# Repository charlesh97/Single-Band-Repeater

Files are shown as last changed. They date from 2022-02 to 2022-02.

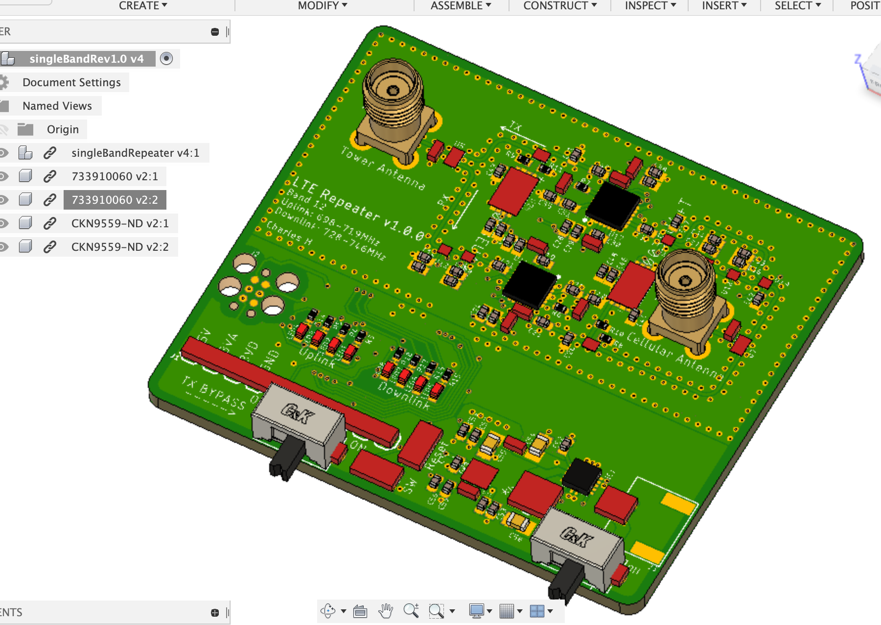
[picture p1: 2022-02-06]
Screen Shot 2020-11-10 at 12.03.37 PM.png

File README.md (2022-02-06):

# Single Band Repeater
## Uplink 698-719MHz
## Downlink 728-746MHz

Archived project. [Schematic](https://gitlab.com/chood2/single-band-repeater/-/blob/main/singleBandRepeater.pdf),[PCB](https://gitlab.com/chood2/single-band-repeater/-/blob/main/Screen%20Shot%202020-11-10%20at%2012.03.37%20PM.png)

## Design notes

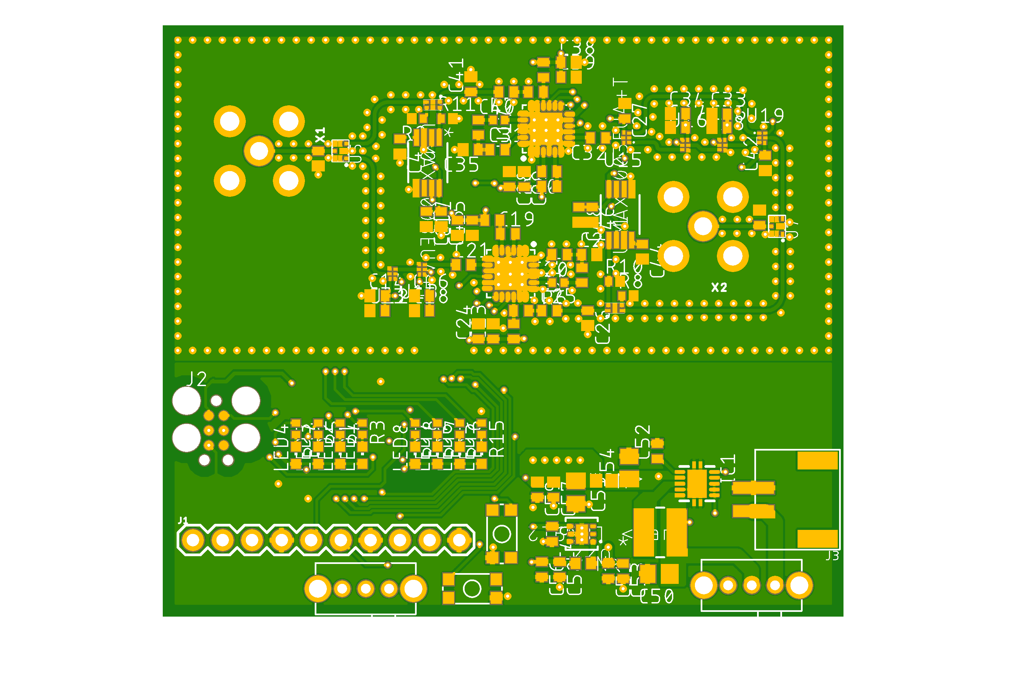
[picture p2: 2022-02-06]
singleBandRepeater.png

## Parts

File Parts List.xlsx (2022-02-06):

Band 5 Duplexer | https://www.digikey.com/product-detail/en/taiyo-yuden/D5DA881M5K2E4-Z/587-5655-1-ND/7251489
Band 12 Duplexer | https://www.digikey.com/product-detail/en/taiyo-yuden/D5DA737M5K2H2-Z/587-4563-1-ND/6024262
LNA | https://www.mouser.com/ProductDetail/Infineon-Technologies/BGA7L1N6E6327XTSA1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
VGA
Antenna | https://www.digikey.com/product-detail/en/taoglas-limited/TG-35-8113/931-1363-ND/5050760
Female Board Mount SMA | https://www.digikey.com/product-detail/en/molex/0733910070/WM5544-ND/1465166
Switch | https://www.infineon.com/dgdl/Infineon-BGS12SN6-DS-v02_03-EN.pdf?fileId=db3a30433f1b26e8013f2db58bc03856

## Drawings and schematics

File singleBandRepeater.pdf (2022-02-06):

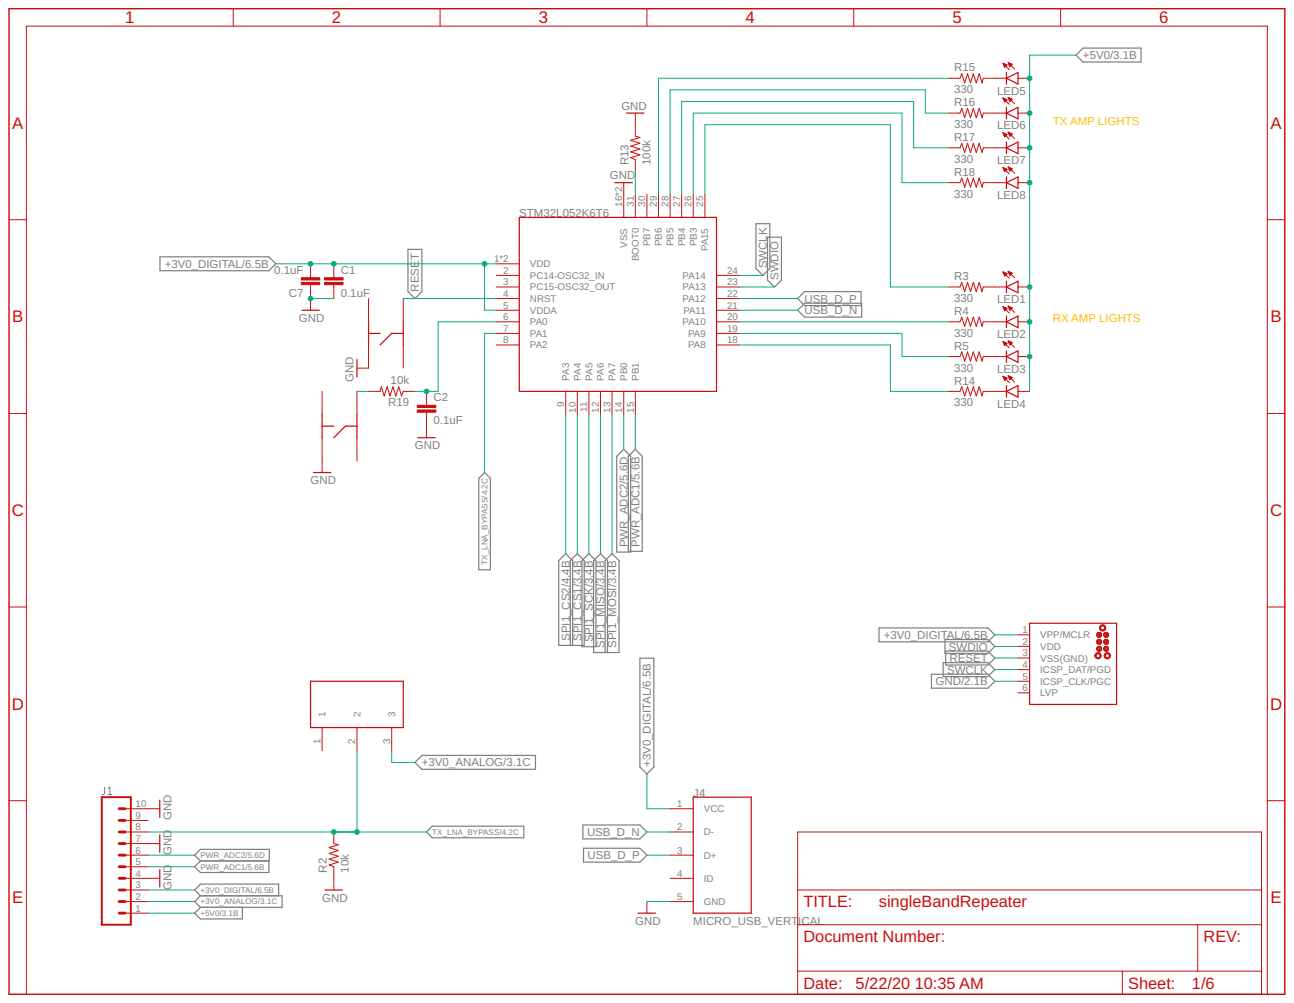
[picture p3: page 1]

Document Number: | REV:

Date: 5/22/20 10:35 AM | Sheet: 1/6

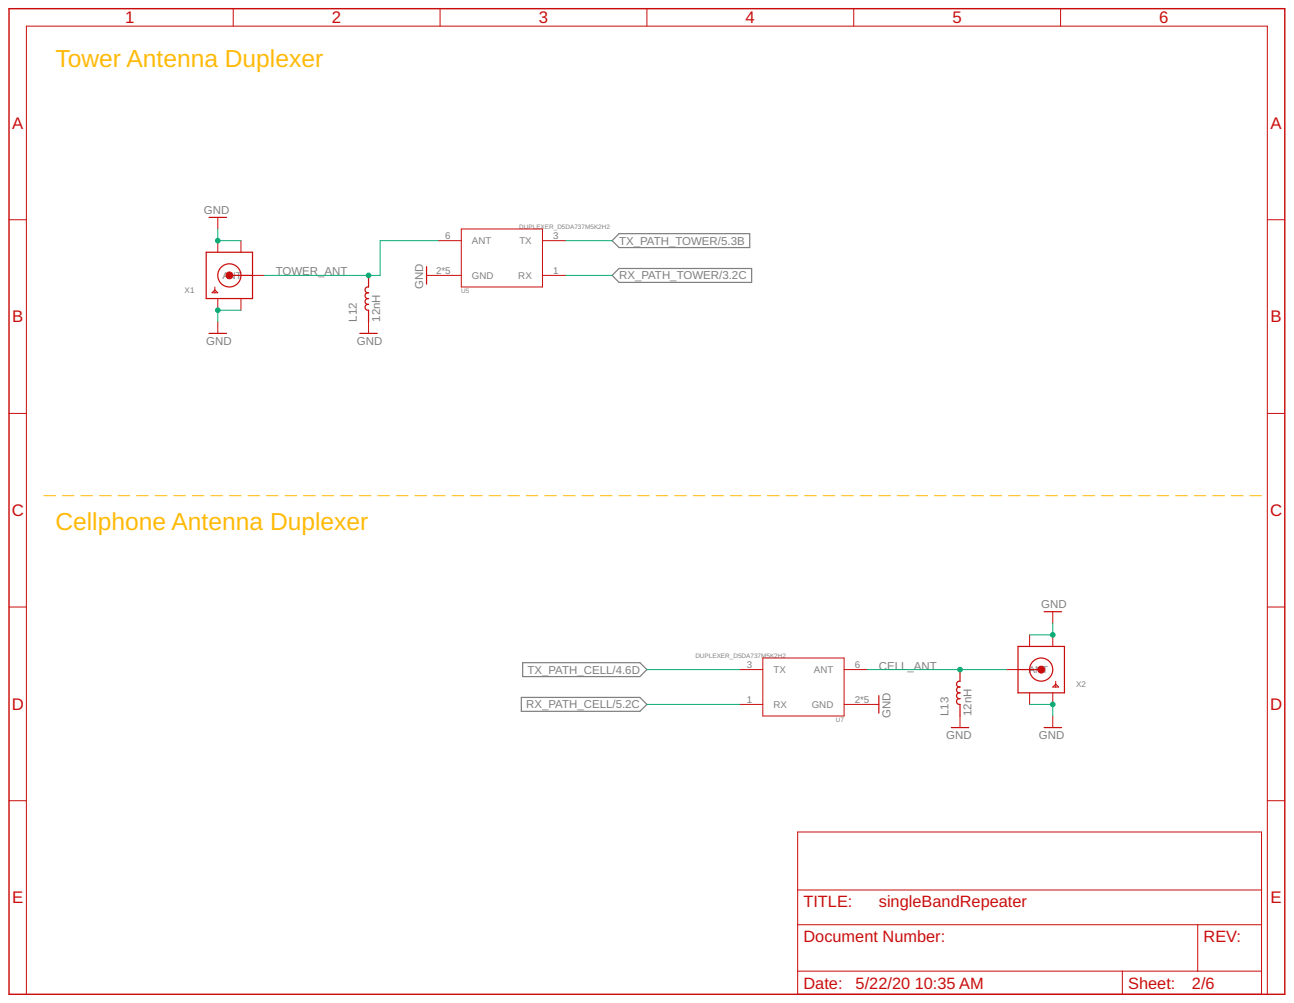
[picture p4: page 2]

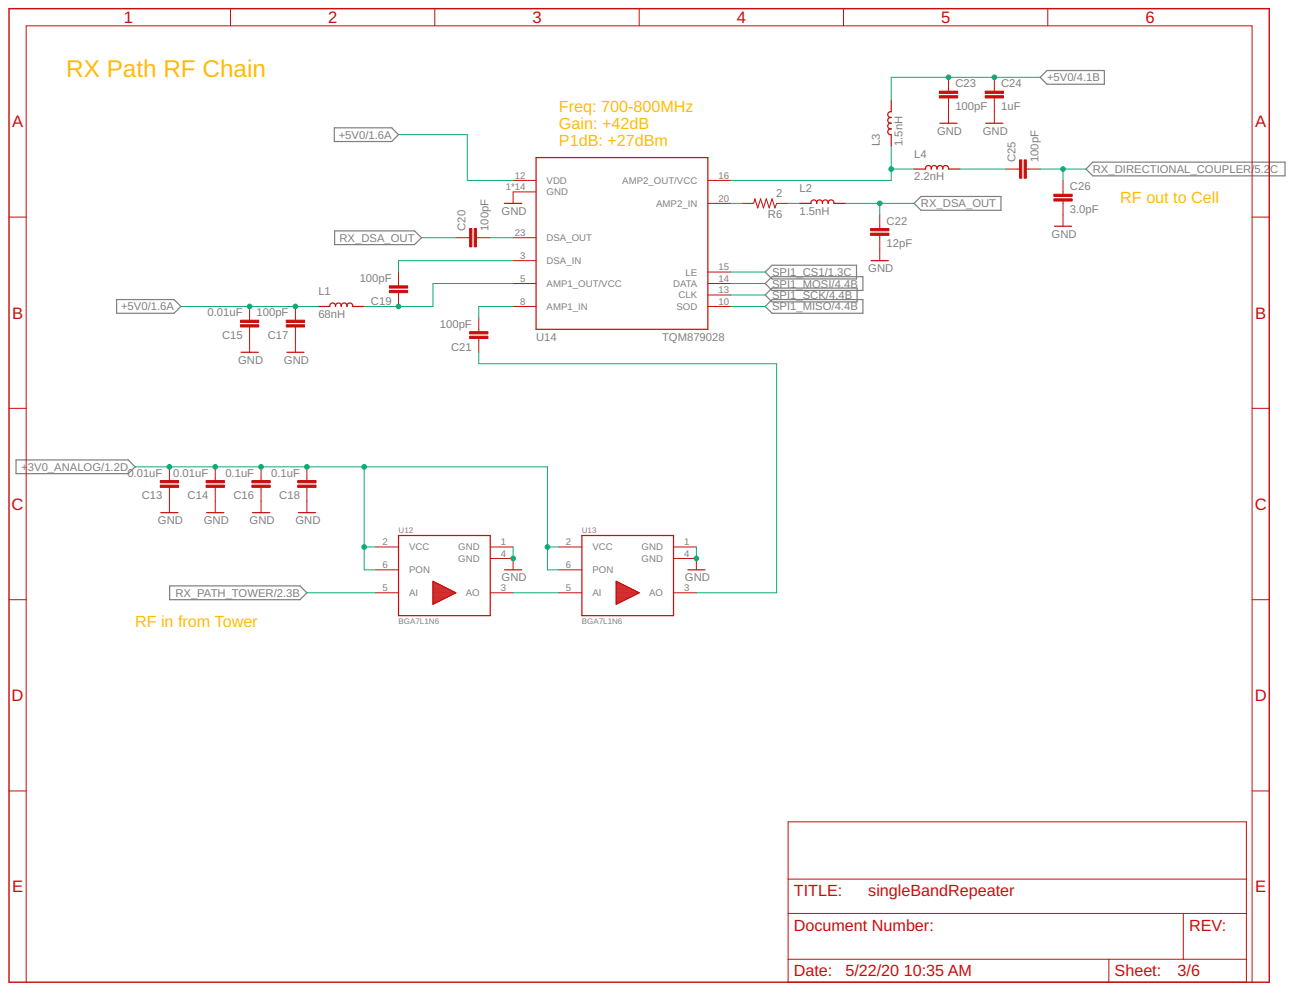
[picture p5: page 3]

RX Path RF Chain

RX_DIRECTIONAL_COUPLER/5.2C
RF out to Cell

RX_PATH_TOWER/2.3B
RF in from Tower

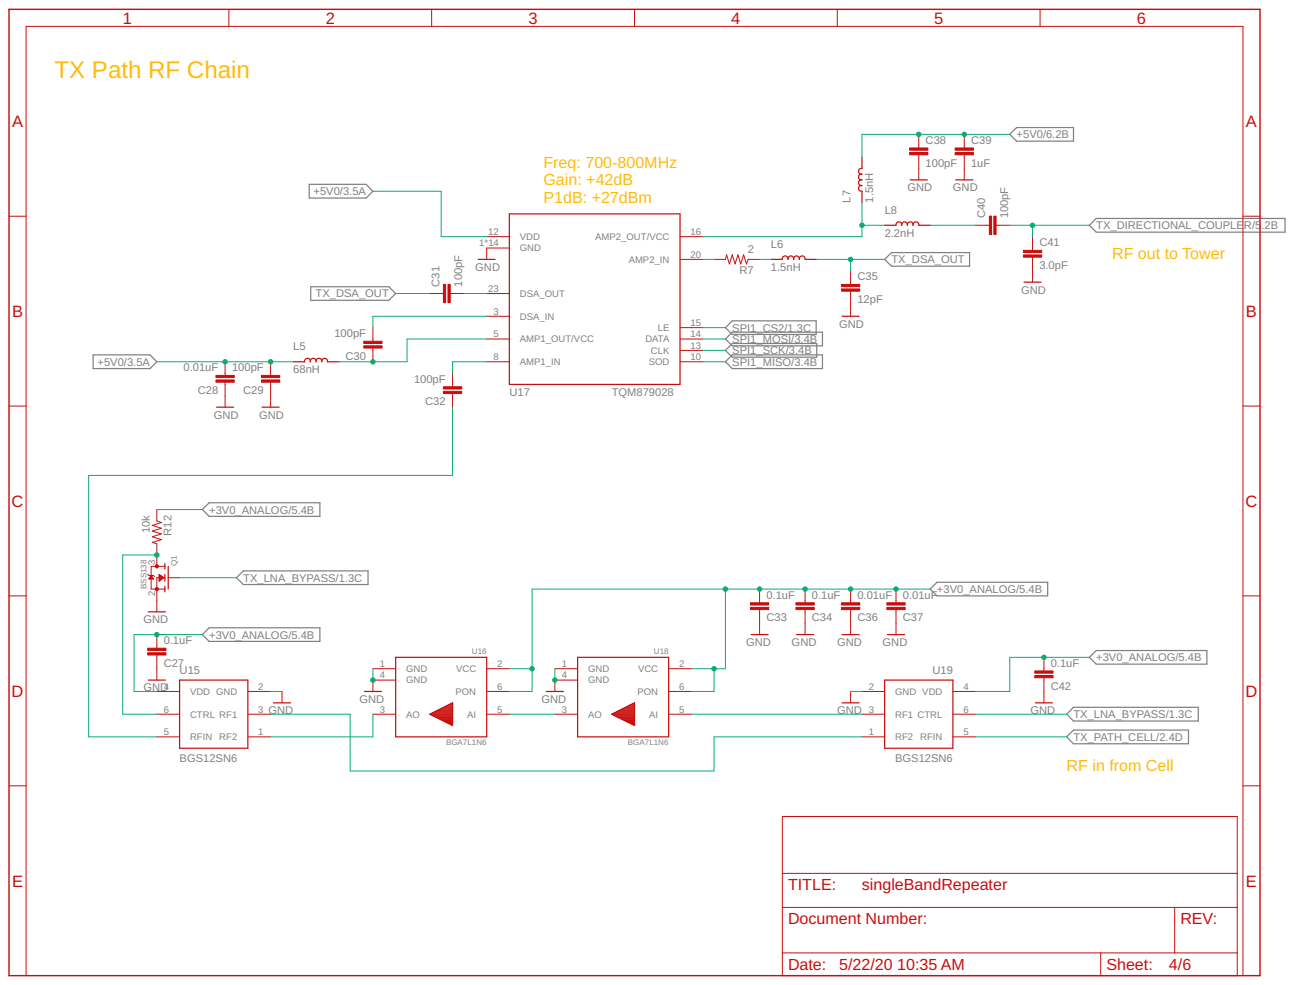
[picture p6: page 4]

TX Path RF Chain

TX_DIRECTIONAL_COUPLER/5.2B
RF out to Tower

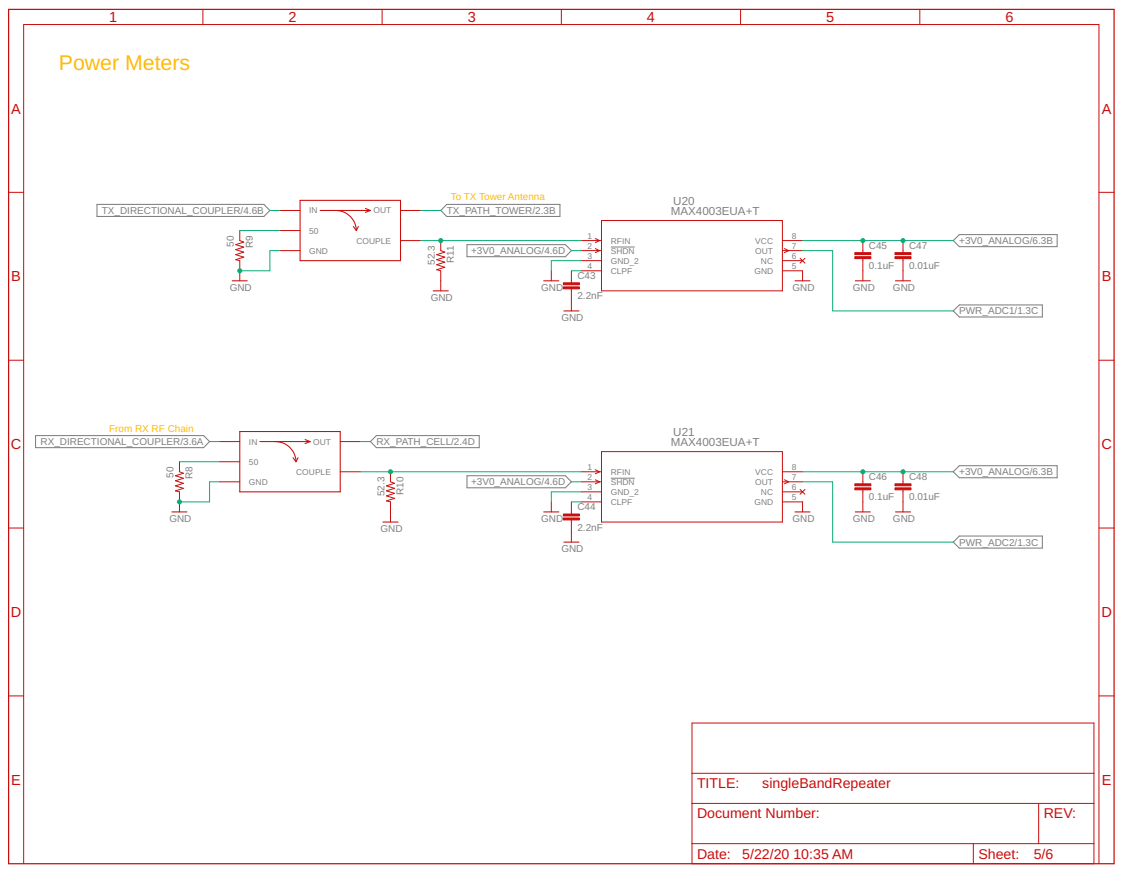
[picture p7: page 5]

To TX Tower Antenna
TX_PATH_TOWER/2.3B

From RX RF Chain

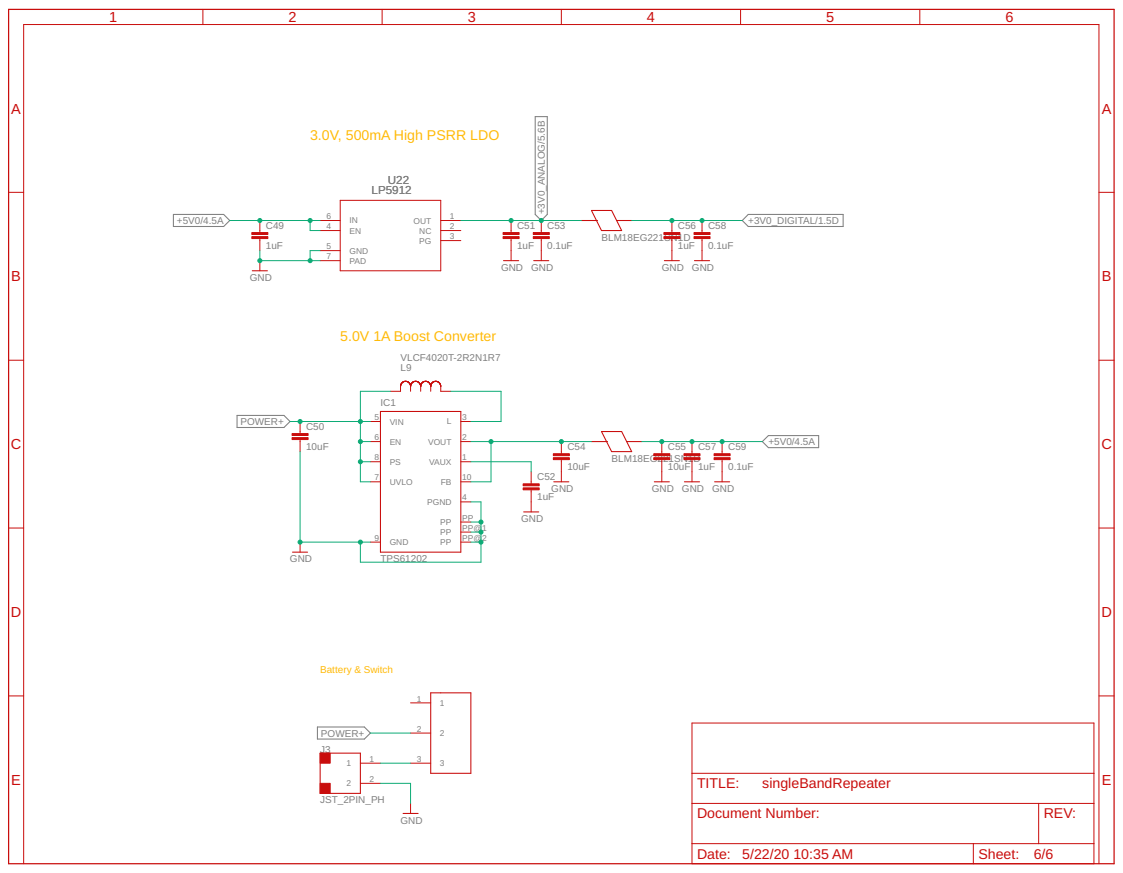
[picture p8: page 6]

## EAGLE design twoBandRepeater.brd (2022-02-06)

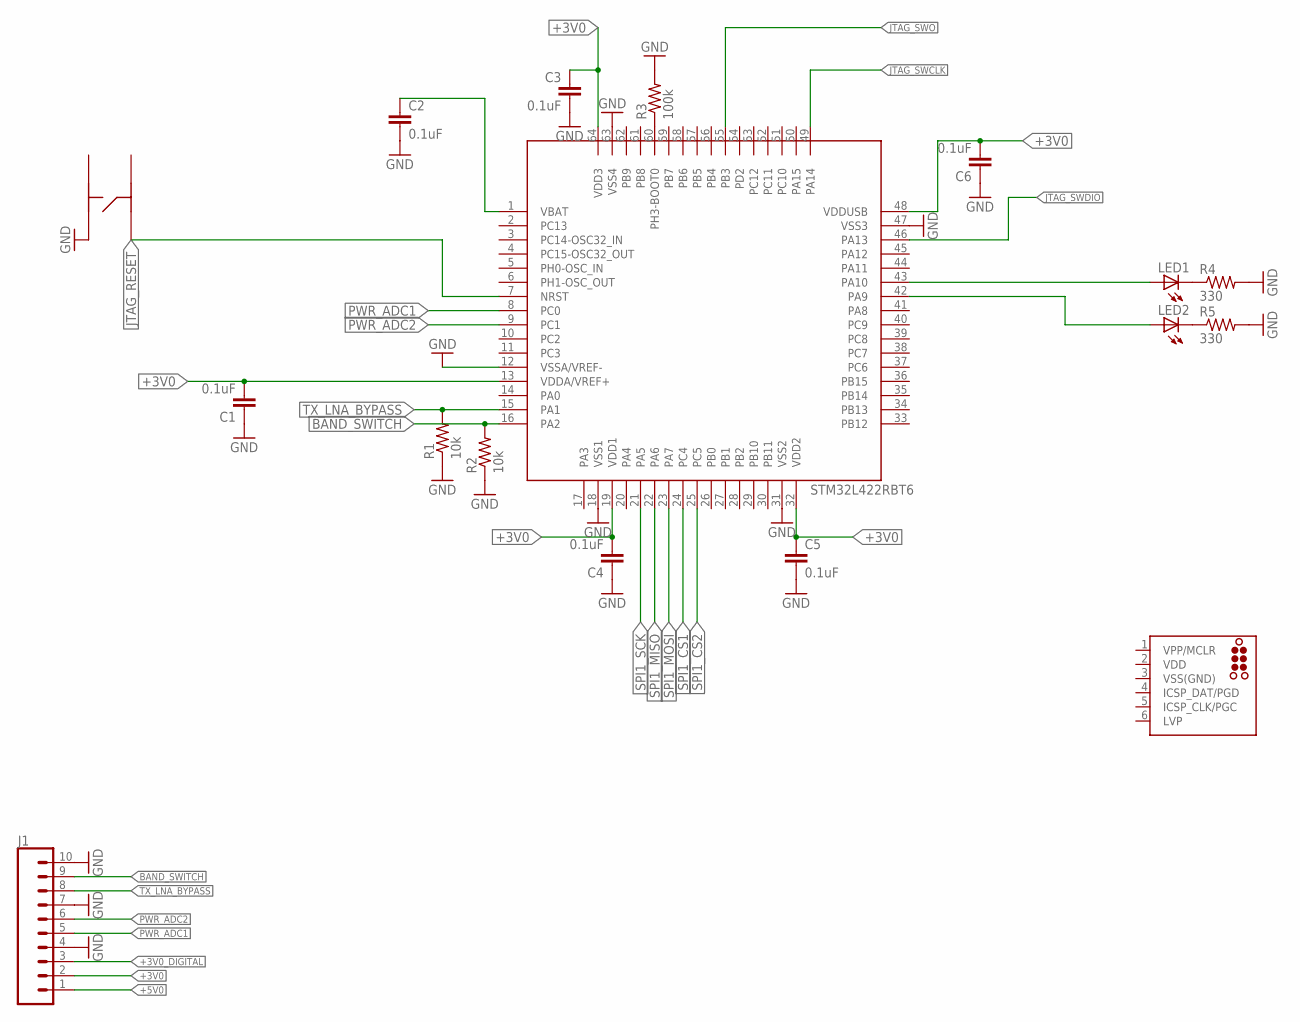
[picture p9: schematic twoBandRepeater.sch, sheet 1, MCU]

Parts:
C1, C2, C3, C4, C5, C6: 0.1uF; C0402
J1: CONN_10"; 1X10
J2: TC2030-MCP
LED1, LED2: LEDCHIP-LED0603; CHIP-LED0603
R1, R2: 10k; R0402
R3: 100k; R0402
R4, R5: 330; R0402
S1: KMR731NG
U1: STM32L422RBT6; QFP50P1200X1200X160-64

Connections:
+3V0: C1.2, C3.1, C4.2, C5.1, C6.2, J1.2, U1.13 (VDDA/VREF+), U1.19 (VDD1), U1.32 (VDD2), U1.48 (VDDUSB), U1.64 (VDD3); also elsewhere on the board
+3V0_DIGITAL: J1.3; also elsewhere on the board
+5V0: J1.1; also elsewhere on the board
BAND_SWITCH: J1.9, R2.2, U1.16 (PA2); also elsewhere on the board
GND: C1.1, C2.2, C3.2, C4.1, C5.2, C6.1, J1.4, J1.7, J1.10, R1.1, R2.1, R3.2, R4.2, R5.2, S1.P$3, U1.12 (VSSA/VREF-), U1.18 (VSS1), U1.31 (VSS2), U1.47 (VSS3), U1.63 (VSS4); also elsewhere on the board
JTAG_RESET: S1.P$2, U1.7 (NRST)
JTAG_SWCLK: U1.49 (PA14)
JTAG_SWDIO: U1.46 (PA13)
JTAG_SWO: U1.55 (PB3)
unnamed: C2.1, U1.1 (VBAT)
unnamed: LED1.C, R4.1
unnamed: LED2.C, R5.1
unnamed: LED2.A, U1.42 (PA9)
unnamed: LED1.A, U1.43 (PA10)
unnamed: R3.1, U1.60 (PH3-BOOT0)
PWR_ADC1: J1.5, U1.8 (PC0); also elsewhere on the board
PWR_ADC2: J1.6, U1.9 (PC1); also elsewhere on the board
SPI1_CS1: U1.24 (PC4); also elsewhere on the board
SPI1_CS2: U1.25 (PC5); also elsewhere on the board
SPI1_MISO: U1.22 (PA6); also elsewhere on the board
SPI1_MOSI: U1.23 (PA7); also elsewhere on the board
SPI1_SCK: U1.21 (PA5); also elsewhere on the board
TX_LNA_BYPASS: J1.8, R1.2, U1.15 (PA1); also elsewhere on the board
VDD: J2.2 (VDD)
VSS(GND): J2.3 (VSS(GND))

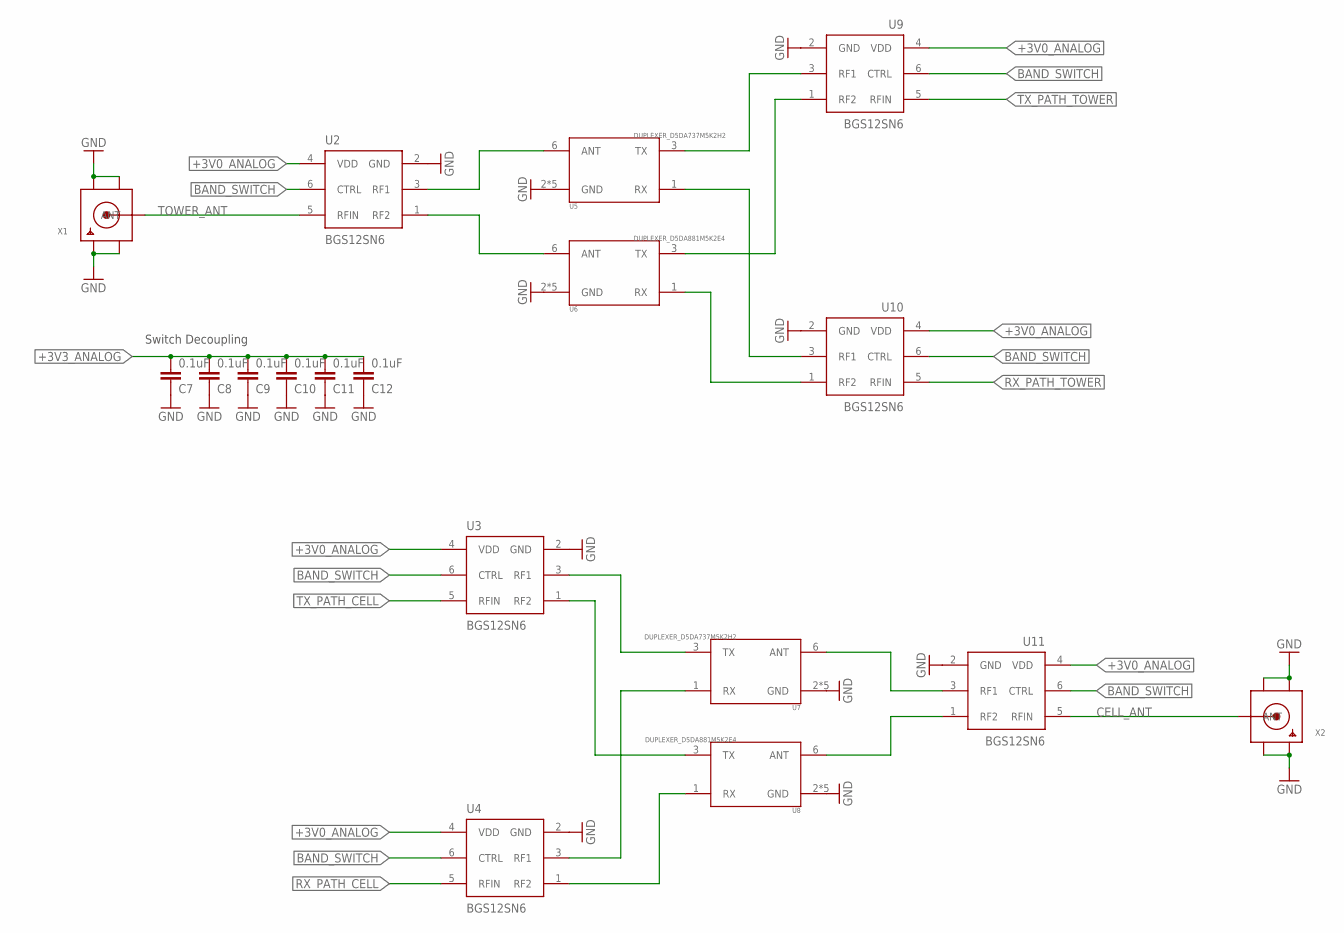
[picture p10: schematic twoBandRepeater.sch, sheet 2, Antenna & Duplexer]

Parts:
C7, C8, C9, C10, C11, C12: 0.1uF; C0402
U2, U3, U4, U9, U10, U11: BGS12SN6; INF-PG-TSNP-6-2
U5, U7: DUPLEXER_D5DA737M5K2H2; TAIYO_YUDEN_DUPLEX_1.8X1.4
U6, U8: DUPLEXER_D5DA881M5K2E4; TAIYO_YUDEN_DUPLEX_1.8X1.4
X1, X2: SMACONNECTORSMA_DIP; SMA_DIP

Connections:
+3V0_ANALOG: U2.4 (VDD), U3.4 (VDD), U4.4 (VDD), U9.4 (VDD), U10.4 (VDD), U11.4 (VDD); also elsewhere on the board
+3V3_ANALOG: C7.2, C8.2, C9.2, C10.2, C11.2, C12.2
BAND_SWITCH: U2.6 (CTRL), U3.6 (CTRL), U4.6 (CTRL), U9.6 (CTRL), U10.6 (CTRL), U11.6 (CTRL); also elsewhere on the board
CELL_ANT: U11.5 (RFIN), X2.ANTENNA (ANT)
GND: C7.1, C8.1, C9.1, C10.1, C11.1, C12.1, U2.2 (GND), U3.2 (GND), U4.2 (GND), U5.2 (GND), U5.4 (GND), U5.5 (GND), U5.7 (GND), U5.8 (GND), U6.2 (GND), U6.4 (GND), U6.5 (GND), U6.7 (GND), U6.8 (GND), U7.2 (GND), U7.4 (GND), U7.5 (GND), U7.7 (GND), U7.8 (GND), U8.2 (GND), U8.4 (GND), U8.5 (GND), U8.7 (GND), U8.8 (GND), U9.2 (GND), U10.2 (GND), U11.2 (GND), X1.GND1, X1.GND2, X1.GND3, X1.GND4, X2.GND1, X2.GND2, X2.GND3, X2.GND4; also elsewhere on the board
unnamed: U2.3 (RF1), U5.6 (ANT)
unnamed: U2.1 (RF2), U6.6 (ANT)
unnamed: U5.3 (TX), U9.3 (RF1)
unnamed: U6.3 (TX), U9.1 (RF2)
unnamed: U5.1 (RX), U10.3 (RF1)
unnamed: U6.1 (RX), U10.1 (RF2)
unnamed: U7.6 (ANT), U11.3 (RF1)
unnamed: U8.6 (ANT), U11.1 (RF2)
unnamed: U3.3 (RF1), U7.3 (TX)
unnamed: U3.1 (RF2), U8.3 (TX)
unnamed: U4.3 (RF1), U7.1 (RX)
unnamed: U4.1 (RF2), U8.1 (RX)
RX_PATH_CELL: U4.5 (RFIN); also elsewhere on the board
RX_PATH_TOWER: U10.5 (RFIN); also elsewhere on the board
TOWER_ANT: U2.5 (RFIN), X1.ANTENNA (ANT)
TX_PATH_CELL: U3.5 (RFIN); also elsewhere on the board
TX_PATH_TOWER: U9.5 (RFIN); also elsewhere on the board

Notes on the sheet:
Switch Decoupling

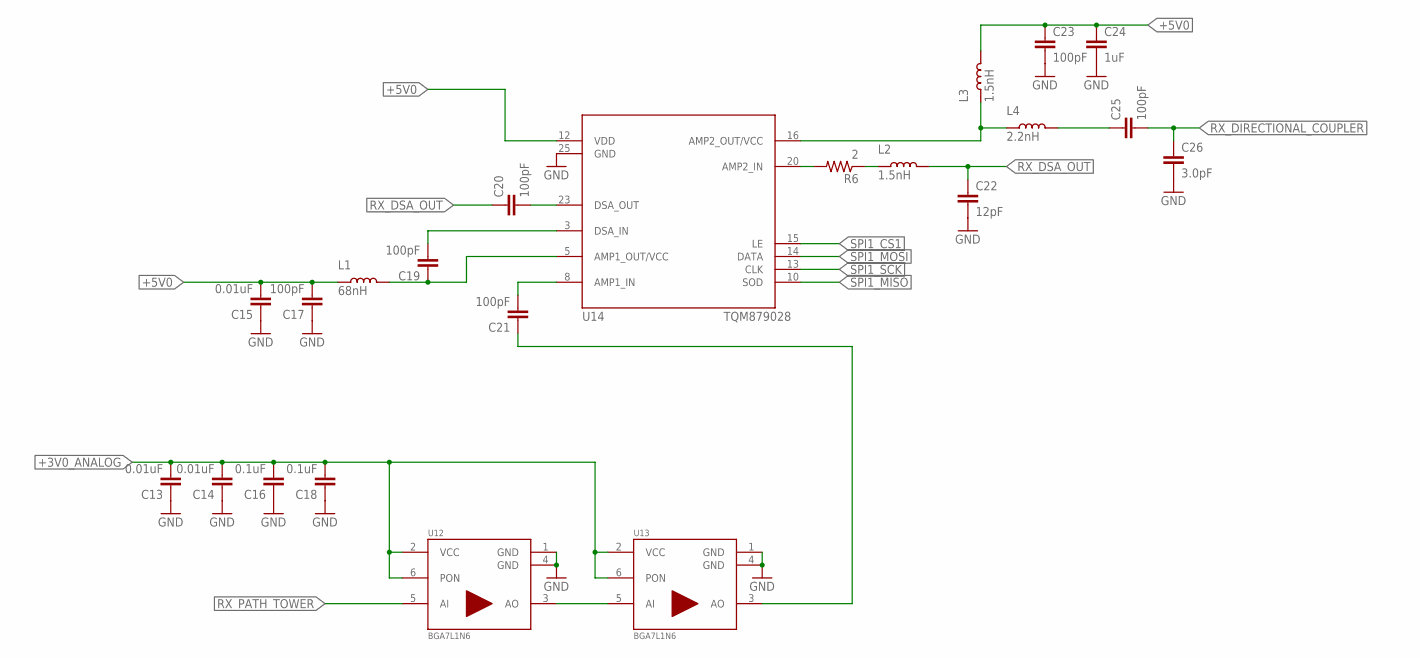
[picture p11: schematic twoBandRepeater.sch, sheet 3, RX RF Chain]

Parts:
C13, C14, C15: 0.01uF; C0402
C16, C18: 0.1uF; C0402
C17, C19, C20, C21, C23, C25: 100pF; C0402
C22: 12pF; C0402
C24: 1uF; C0402
C26: 3.0pF; C0402
L1: 68nH; 0402
L2, L3: 1.5nH; 0402
L4: 2.2nH; 0402
R6: 2; R0402
U12, U13: BGA7L1N6; INF-PG-TSNP-6-2
U14: TQM879028; QFN50P400X400X100-25T270N

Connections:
+3V0_ANALOG: C13.2, C14.2, C16.2, C18.2, U12.2 (VCC), U12.6 (PON), U13.2 (VCC), U13.6 (PON); also elsewhere on the board
+5V0: C15.2, C17.2, C23.1, C24.1, L1.1, L3.2, U14.12 (VDD); also elsewhere on the board
GND: C13.1, C14.1, C15.1, C16.1, C17.1, C18.1, C22.2, C23.2, C24.2, C26.2, U12.1 (GND), U12.4 (GND), U13.1 (GND), U13.4 (GND), U14.25 (GND); also elsewhere on the board
unnamed: U12.3 (AO), U13.5 (AI)
unnamed: C21.1, U13.3 (AO)
unnamed: C21.2, U14.8 (AMP1_IN)
unnamed: C19.1, L1.2, U14.5 (AMP1_OUT/VCC)
unnamed: C20.2, U14.23 (DSA_OUT)
unnamed: C19.2, U14.3 (DSA_IN)
unnamed: L3.1, L4.1, U14.16 (AMP2_OUT/VCC)
unnamed: L2.1, R6.1
unnamed: R6.2, U14.20 (AMP2_IN)
unnamed: C25.1, L4.2
RX_DIRECTIONAL_COUPLER: C25.2, C26.1; also elsewhere on the board
RX_DSA_OUT: C20.1, C22.1, L2.2
RX_PATH_TOWER: U12.5 (AI); also elsewhere on the board
SPI1_CS1: U14.15 (LE); also elsewhere on the board
SPI1_MISO: U14.10 (SOD); also elsewhere on the board
SPI1_MOSI: U14.14 (DATA); also elsewhere on the board
SPI1_SCK: U14.13 (CLK); also elsewhere on the board

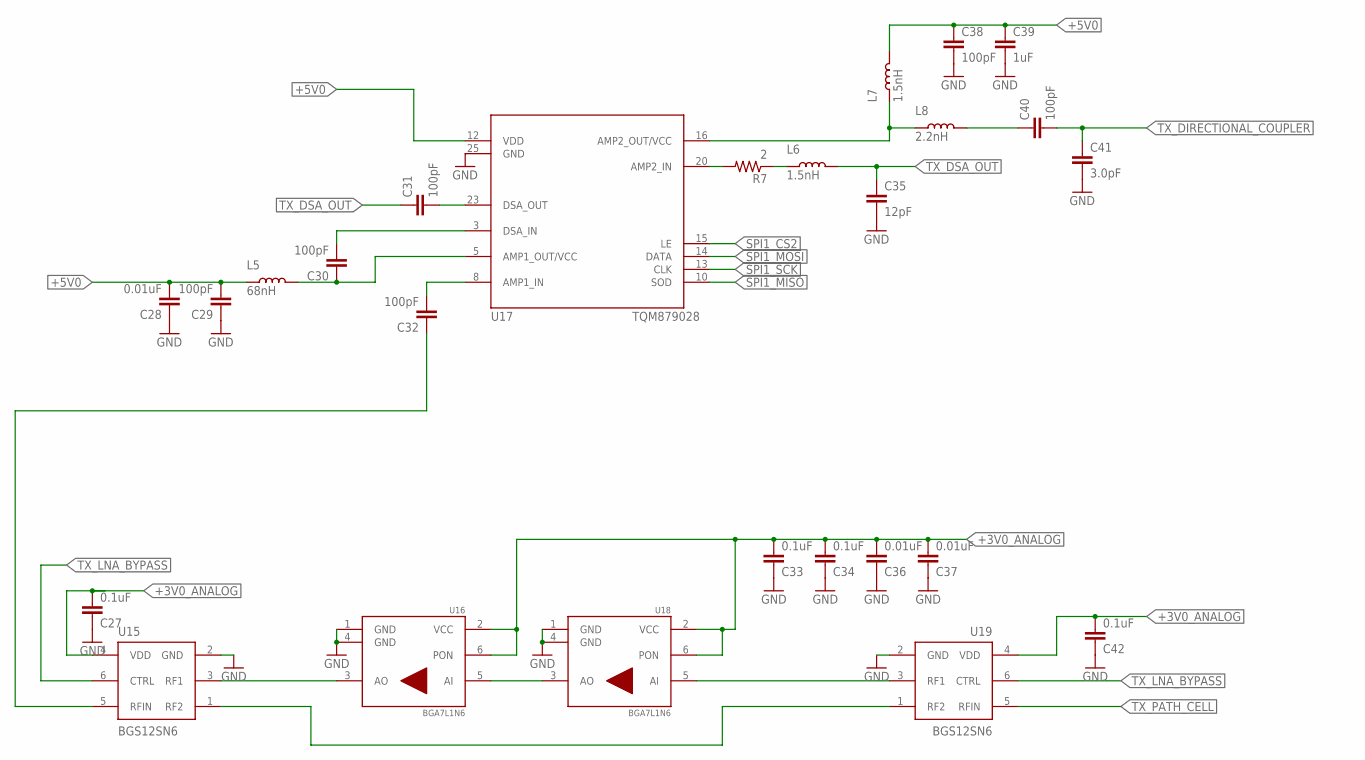
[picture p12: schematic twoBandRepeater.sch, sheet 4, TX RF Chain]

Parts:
C27, C33, C34, C42: 0.1uF; C0402
C28, C36, C37: 0.01uF; C0402
C29, C30, C31, C32, C38, C40: 100pF; C0402
C35: 12pF; C0402
C39: 1uF; C0402
C41: 3.0pF; C0402
L5: 68nH; 0402
L6, L7: 1.5nH; 0402
L8: 2.2nH; 0402
R7: 2; R0402
U15, U19: BGS12SN6; INF-PG-TSNP-6-2
U16, U18: BGA7L1N6; INF-PG-TSNP-6-2
U17: TQM879028; QFN50P400X400X100-25T270N

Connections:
+3V0_ANALOG: C27.2, C33.2, C34.2, C36.2, C37.2, C42.2, U15.4 (VDD), U16.2 (VCC), U16.6 (PON), U18.2 (VCC), U18.6 (PON), U19.4 (VDD); also elsewhere on the board
+5V0: C28.2, C29.2, C38.1, C39.1, L5.1, L7.2, U17.12 (VDD); also elsewhere on the board
GND: C27.1, C28.1, C29.1, C33.1, C34.1, C35.2, C36.1, C37.1, C38.2, C39.2, C41.2, C42.1, U15.2 (GND), U16.1 (GND), U16.4 (GND), U17.25 (GND), U18.1 (GND), U18.4 (GND), U19.2 (GND); also elsewhere on the board
unnamed: U16.5 (AI), U18.3 (AO)
unnamed: C32.2, U17.8 (AMP1_IN)
unnamed: C30.1, L5.2, U17.5 (AMP1_OUT/VCC)
unnamed: C30.2, U17.3 (DSA_IN)
unnamed: C31.2, U17.23 (DSA_OUT)
unnamed: L6.1, R7.1
unnamed: R7.2, U17.20 (AMP2_IN)
unnamed: L7.1, L8.1, U17.16 (AMP2_OUT/VCC)
unnamed: C40.1, L8.2
unnamed: U15.3 (RF1), U16.3 (AO)
unnamed: U18.5 (AI), U19.3 (RF1)
unnamed: U15.1 (RF2), U19.1 (RF2)
unnamed: C32.1, U15.5 (RFIN)
SPI1_CS2: U17.15 (LE); also elsewhere on the board
SPI1_MISO: U17.10 (SOD); also elsewhere on the board
SPI1_MOSI: U17.14 (DATA); also elsewhere on the board
SPI1_SCK: U17.13 (CLK); also elsewhere on the board
TX_DIRECTIONAL_COUPLER: C40.2, C41.1; also elsewhere on the board
TX_DSA_OUT: C31.1, C35.1, L6.2
TX_LNA_BYPASS: U15.6 (CTRL), U19.6 (CTRL); also elsewhere on the board
TX_PATH_CELL: U19.5 (RFIN); also elsewhere on the board

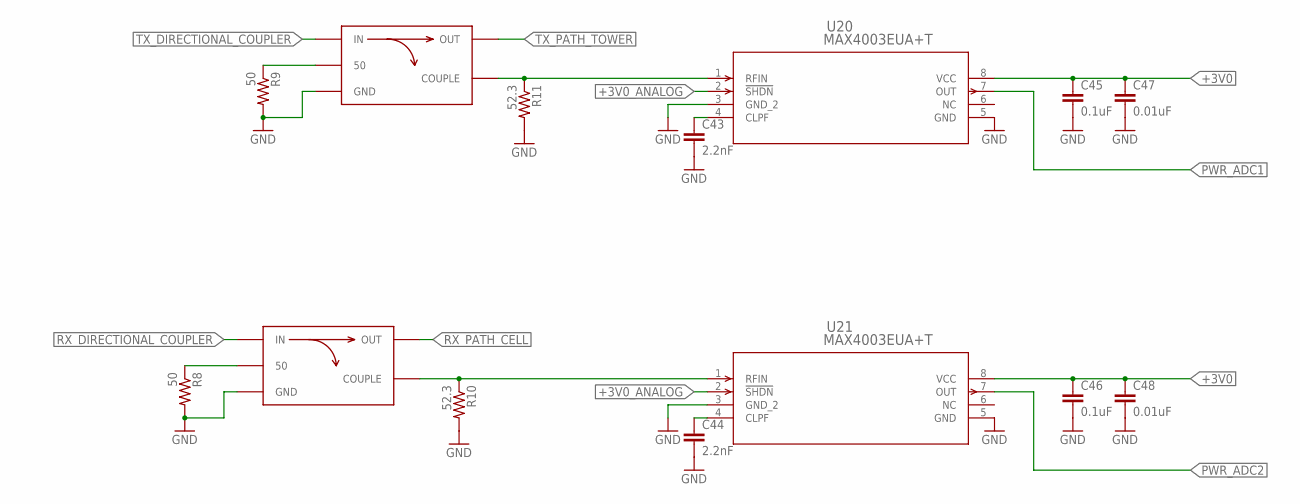
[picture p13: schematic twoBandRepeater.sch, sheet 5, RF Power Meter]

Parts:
C43, C44: 2.2nF; C0402
C45, C46: 0.1uF; C0402
C47, C48: 0.01uF; C0402
HY1, HY2: HHM22152A2
R8, R9: 50; R0402
R10, R11: 52.3; R0402
U20, U21: MAX4003EUA+T; 21-0036K

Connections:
+3V0: C45.1, C46.1, C47.1, C48.1, U20.8 (VCC), U21.8 (VCC); also elsewhere on the board
+3V0_ANALOG: U20.2 (!SHDN), U21.2 (!SHDN); also elsewhere on the board
GND: C43.2, C44.2, C45.2, C46.2, C47.2, C48.2, HY1.P$2 (GND), HY1.P$5 (GND), HY2.P$2 (GND), HY2.P$5 (GND), R8.2, R9.2, R10.2, R11.2, U20.3 (GND_2), U20.5 (GND), U21.3 (GND_2), U21.5 (GND); also elsewhere on the board
unnamed: HY2.P$4 (50), R9.1
unnamed: C43.1, U20.4 (CLPF)
unnamed: HY2.P$6 (COUPLE), R11.1, U20.1 (RFIN)
unnamed: HY1.P$4 (50), R8.1
unnamed: C44.1, U21.4 (CLPF)
unnamed: HY1.P$6 (COUPLE), R10.1, U21.1 (RFIN)
PWR_ADC1: U20.7 (OUT); also elsewhere on the board
PWR_ADC2: U21.7 (OUT); also elsewhere on the board
RX_DIRECTIONAL_COUPLER: HY1.P$1 (IN); also elsewhere on the board
RX_PATH_CELL: HY1.P$3 (OUT); also elsewhere on the board
TX_DIRECTIONAL_COUPLER: HY2.P$1 (IN); also elsewhere on the board
TX_PATH_TOWER: HY2.P$3 (OUT); also elsewhere on the board

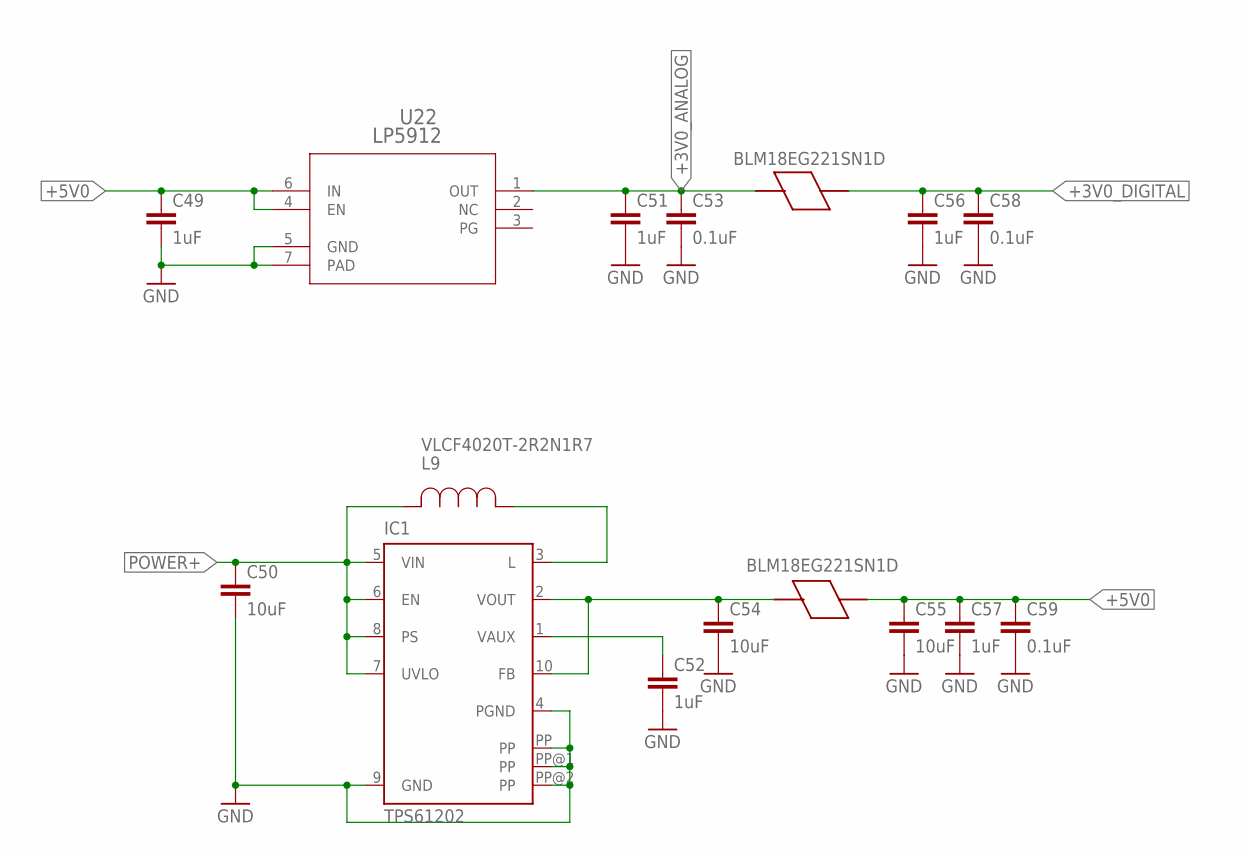
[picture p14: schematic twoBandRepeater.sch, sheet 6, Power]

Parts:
C49, C51, C52, C56, C57: 1uF; C0402
C50, C54, C55: 10uF; C0805
C53, C58, C59: 0.1uF; C0402
IC1: TPS61202; S-PDSO-N10
L9: VLCF4020T-2R2N1R7; IND_4028
L10, L11: BLM18EG221SN1D; IND_BLM18_0603
U22: LP5912; DRV0006A

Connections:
+3V0_ANALOG: C51.1, C53.1, L10.1, U22.1 (OUT); also elsewhere on the board
+3V0_DIGITAL: C56.1, C58.1, L10.2; also elsewhere on the board
+5V0: C49.1, C55.1, C57.1, C59.1, L11.2, U22.4 (EN), U22.6 (IN); also elsewhere on the board
GND: C49.2, C50.2, C51.2, C52.2, C53.2, C54.2, C55.2, C56.2, C57.2, C58.2, C59.2, IC1.4 (PGND), IC1.9 (GND), IC1.PP, IC1.PP@1 (PP), IC1.PP@2 (PP), U22.5 (GND), U22.7 (PAD); also elsewhere on the board
unnamed: IC1.3 (L), L9.1
unnamed: C54.1, IC1.2 (VOUT), IC1.10 (FB), L11.1
unnamed: C52.1, IC1.1 (VAUX)
POWER+: C50.1, IC1.5 (VIN), IC1.6 (EN), IC1.7 (UVLO), IC1.8 (PS), L9.2

Board: 2 copper layers, 113 parts (0 on the bottom side), 77 nets, no tracks yet.

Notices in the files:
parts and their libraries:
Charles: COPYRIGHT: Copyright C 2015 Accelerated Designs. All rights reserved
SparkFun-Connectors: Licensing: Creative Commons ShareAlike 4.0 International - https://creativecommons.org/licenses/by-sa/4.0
